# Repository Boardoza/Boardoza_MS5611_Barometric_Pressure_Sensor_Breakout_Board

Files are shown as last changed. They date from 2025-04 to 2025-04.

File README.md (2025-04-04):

# Boardoza MS5611 Barometric Pressure Sensor Breakout Board

The **Boardoza MS5611** is a **high-precision barometric pressure sensor module** designed for **altitude measurement, weather monitoring, and industrial pressure sensing**. It integrates the **MS5611-01BA03** digital pressure sensor, providing accurate pressure readings with ultra-low power consumption.  

This module operates with **3.3V or 5V**, making it compatible with a wide range of microcontrollers. It communicates via **I<sup>2</sup>C by default**, but can be switched to **SPI mode** using the **PS pin**. The **CSB, SDO, and PS pins operate at 3.3V**, ensuring easy interfacing with low-power microcontrollers.  

## [Click here to purchase!](https://www.ozdisan.com/maker-ve-iot-urunleri/boardoza/boardoza-modulleri/BOARDOZA-MS5611/1202433)

|Front Side|Back Side|
|:---:|:---:|
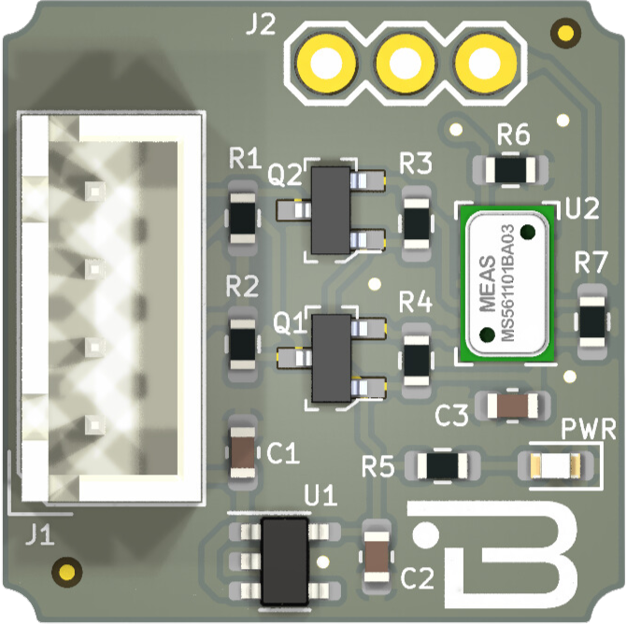
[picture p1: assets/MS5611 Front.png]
MS5611 Front
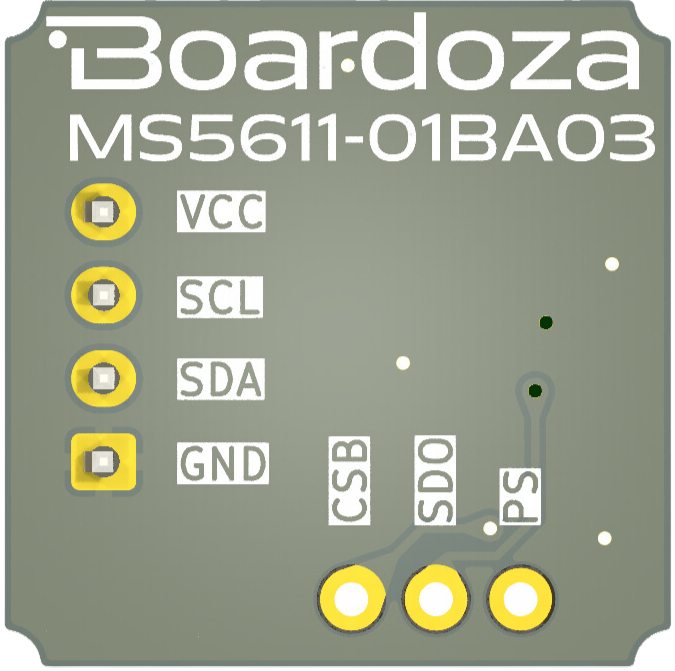
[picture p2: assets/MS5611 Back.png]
MS5611 Back
| | |

---

## Key Features

- **High-Precision Barometric Pressure Sensor:** Ideal for altitude measurement, weather monitoring, and UAV applications.  
- **24-bit High-Resolution Output:** Ultra-precise pressure measurement using an integrated 24-bit ADC.  
- **Flexible Power Compatibility:** Operates with **3.3V or 5V**, making it suitable for various MCUs.  
- **I<sup>2</sup>C and SPI Support:** Default interface is **I<sup>2</sup>C**, but can be configured to **SPI mode** using the **PS pin**.  
- **Ultra-Low Power Consumption:** Optimized for battery-powered applications.  

---

## Technical Specifications

**Model:** MS5611-01BA03  
**Input Voltage:** 3.3V - 5.5V  
**Voltage Input Type:** 4-pin 2.50mm header  
**Interface:** I<sup>2</sup>C (default), SPI (configurable)  
**Functions:** High-Precision Barometric Pressure Measurement  
**ADC Resolution:** 24-bit  
**Operating Pressure Range:** 450 to 1100 mbar (Full Accuracy)  
**Extended Pressure Range:** 10 to 1200 mbar (Linear ADC Range)  
**Operating Temperature:** -40°C ~ +85°C  
**Board Dimensions:** 20mm x 20mm  

---

## Board Pinout

### **( J1 ) I<sup>2</sup>C Communication Pins**  

| Pin Number | Pin Name | Description |
|:---:|:---:|---|
| 1 | VCC | Power Supply (3.3V - 5.5V) |
| 2 | SCL | I<sup>2</sup>C Serial Clock Pin |
| 3 | SDA | I<sup>2</sup>C Serial Data Pin |
| 4 | GND | Ground |

### **( J2 ) SPI Mode & Configuration Pins**  

| Pin Number | Pin Name | Description |
|:---:|:---:|---|
| 1 | CSB | Chip select (active low), internally pulled down to ground with a pull-down resistor. |
| 2 | SDO | Serial data output. |
| 3 | PS | Protocol selection:<ul><li>PS High (3.3V) = I<sup>2</sup>C (Default address: 0x77)</li><li>PS Low (GND) = SPI Mode</li></ul> (Internally pulled up to 3.3V with a pull-up resistor). |

---

## Board Dimensions

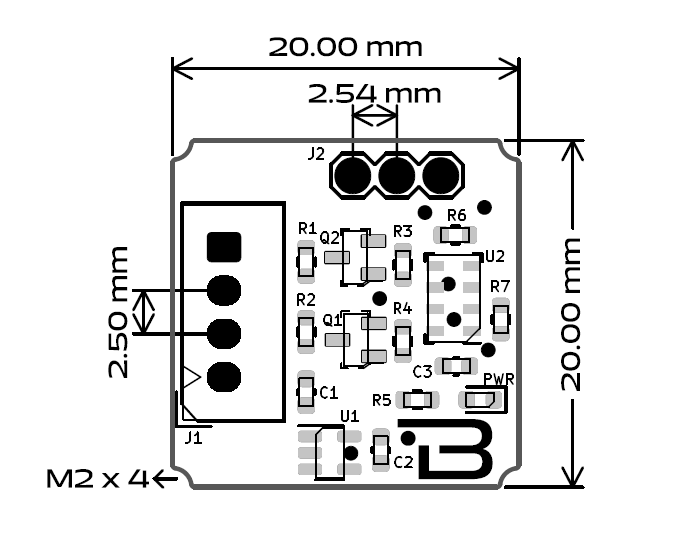
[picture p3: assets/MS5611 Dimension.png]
MS5611 Dimension


---

## Step Files

[Boardoza MS5611.step](./assets/MS5611%20Step.step)

---

## Datasheet

[Boardoza MS5611 Datasheet.pdf](./assets/MS5611%20Datasheet.pdf)

---

## Version History

- V1.0.0 - Initial Release

---

## Support

- If you have any questions or need support, please contact <support@boardoza.com>

---

## License

Shield: [][cc-by-sa]

This work is licensed under a [Creative Commons Attribution-ShareAlike 4.0 International License][cc-by-sa].

[][cc-by-sa]

[cc-by-sa]: http://creativecommons.org/licenses/by-sa/4.0/
[cc-by-sa-image]: https://licensebuttons.net/l/by-sa/4.0/88x31.png
[cc-by-sa-shield]: https://img.shields.io/badge/License-CC%20BY--SA%204.0-lightgrey.svg

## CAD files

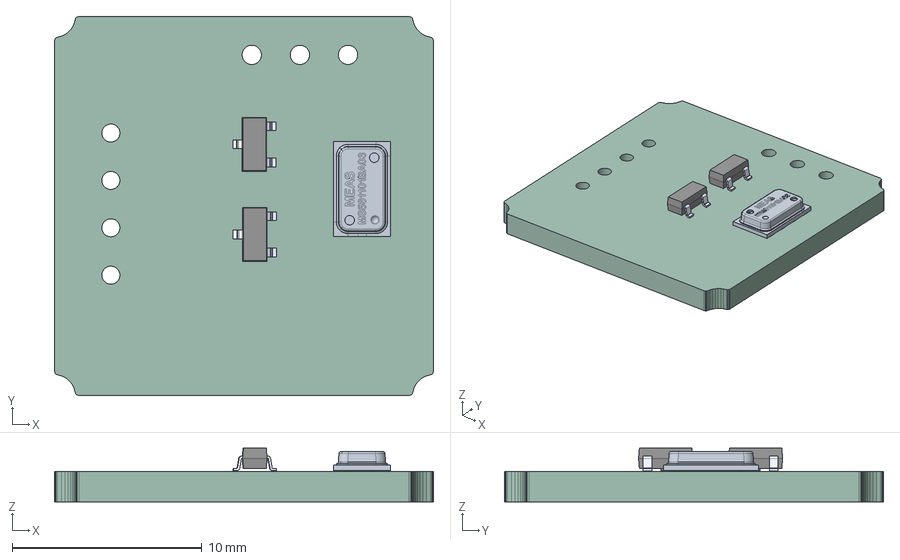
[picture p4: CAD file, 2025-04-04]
assets/MS5611 Step.step
20.0 x 20.0 x 2.83 mm
MAX6103EUR-T x 2
Document
B-MS5611-Brk-01Mbr-R01 PCB

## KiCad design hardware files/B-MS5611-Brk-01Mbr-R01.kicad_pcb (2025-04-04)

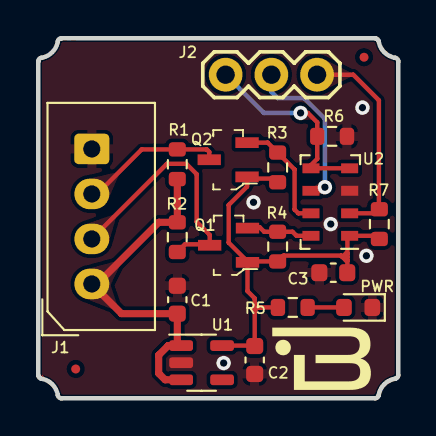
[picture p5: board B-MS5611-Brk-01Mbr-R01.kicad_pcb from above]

Board: 2 copper layers, 20.0 x 20.0 mm, 17 parts (0 on the bottom side), 11 nets.

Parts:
C1, C2: 1uF; C_0603_1608Metric
C3: 100nF; C_0603_1608Metric
J1: MOLEX_CONNECTOR_1X4; 2317-04S_1x04_P2.50mm_Vertical
J2: CONN_03; 1X03
PWR: LED POWER; LED_0603_1608Metric
Q1, Q2: 2N7002_R1_00001; SOT-23-3
R1, R2, R3, R4, R5, R6, R7: 10K; R_0603_1608Metric
U1: TLV73333PDBVR; SOT-23-5
U2: MS5611-01BA; LGA-8_3x5mm_P1.25mm

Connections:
+3V3: C2.1, C3.1, Q1.1 (G), Q2.1 (G), R3.1, R4.1, R5.1, R7.2, U1.5 (OUT), U2.1 (VDD)
CSB: J2.3, R6.1, U2.4 (CSB), U2.5 (CSB)
GND: C1.2, C2.2, C3.2, J1.4, PWR.1 (K), R6.2, U1.2 (GND), U2.3 (GND)
unnamed: PWR.2 (A), R5.2
PS: J2.1, R7.1, U2.2 (PS)
SCL: J1.2, Q1.3 (D), R2.2
SCL_3.3: Q1.2 (S), R4.2, U2.8 (SCLK)
SDA: J1.3, Q2.3 (D), R1.2
SDA_3.3: Q2.2 (S), R3.2, U2.7 (SDI/SDA)
SDO: J2.2, U2.6 (SDO)
VCC: C1.1, J1.1, R1.1, R2.1, U1.1 (IN), U1.3 (EN)

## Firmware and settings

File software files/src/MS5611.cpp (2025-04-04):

#include "MS5611.h"

/**
 * @brief Performs initialization routines.
 *
 * @param osr Oversampling rate for MS5611.
 * @return A boolean value indicating whether the initialization was successful or not.
 *
 * This function initializes the MS5611 sensor and performs necessary initialization routines.
 * First, it starts the Wire library and sends a reset signal to the sensor. Then, it sets
 * the specified oversampling rate and waits for a certain period of time. Finally, it
 * retrieves calibration data and returns a boolean value indicating the success of the operation.
 */
bool MS5611::begin(MS5611_osr osr) {
    Wire.begin();

    performReset();

    setOversampling(osr);

    delay(100);

    getCalibrationData();

    return true;
}

MS5611::MS5611() {
    
}

/**
 * @brief Sets the oversampling rate for the MS5611 sensor.
 *
 * @param osr Oversampling rate to be set.
 *
 * This function sets the oversampling rate for the MS5611 sensor based on the provided parameter.
 * The oversampling rate determines the number of samples taken by the sensor for each measurement,
 * affecting the resolution and accuracy of the readings. The function uses a switch statement to
 * determine the appropriate counter value based on the oversampling rate parameter. The counter
 * value is then assigned to the `counter` member variable and the `userOversamplingRate` member
 * variable is updated with the provided oversampling rate.
 */
void MS5611::setOversampling(MS5611_osr osr) {
    switch (osr)
    {
    case ULTRA_LOW_POWER:
    counter = 1;
        break;
    case LOW_POWER:
    counter = 2;
        break;
    case STANDARD:
    counter = 3;
        break;
    case HIGH_RES:
    counter = 5;
        break;
    case ULTRA_HIGH_RES:
    counter = 10;
        break;
    default:
        break;
    }
    userOversamplingRate = osr;
}

/**
 * @brief Retrieves the current oversampling rate set for the MS5611 sensor.
 *
 * @return The current oversampling rate as an MS5611_osr enum value.
 *
 * This function returns the current oversampling rate that has been set for the MS5611 sensor.
 * The oversampling rate determines the number of samples taken by the sensor for each measurement,
 * affecting the resolution and accuracy of the readings. The function simply returns the value of
 * the `userOversamplingRate` member variable, which holds the current oversampling rate.
 */
uint8_t MS5611::getOversampling(void) {
    return static_cast<uint8_t>(userOversamplingRate);
}

/**
 * @brief Performs a reset operation on the MS5611 sensor.
 *
 * This function sends a reset signal to the MS5611 sensor to perform a reset operation.
 * It starts a transmission using the Wire library to the MS5611 sensor's address and writes
 * the reset command (MS5611_RESET). Finally, it ends the transmission.
 */
void MS5611::performReset(void) {
    Wire.beginTransmission(MS5611_ADDRESS);
    Wire.write(MS5611_RESET);
    Wire.endTransmission();
}

/**
 * @brief Retrieves calibration data from the MS5611 sensor.
 *
 * This function retrieves calibration data from the MS5611 sensor by reading the
 * appropriate registers. It uses a for loop to iterate over the calibration data
 * registers and reads 16 bits of data from each register. The retrieved data is then
 * stored in the `filterCoefficient` array, which holds the calibration coefficients
 * used for sensor measurements.
 */ 
void MS5611::getCalibrationData(void) {
    for(uint8_t offset = 0; offset < 6; offset++) {
        filterCoefficient[offset] = readRegister16(MS5611_READ_PROM + (offset * 2));
    }
}

/**
 * @brief Reads the raw temperature value from the MS5611 sensor.
 *
 * @return The raw temperature value as a 32-bit unsigned integer.
 *
 * This function reads the raw temperature value from the MS5611 sensor. It starts a transmission
 * using the Wire library to the MS5611 sensor's address and writes the conversion command (MS5611_CONV_D2)
 * along with the user-specified oversampling rate. It then ends the transmission and waits for a certain
 * delay based on the oversampling rate. Finally, it reads a 24-bit value from the ADC read register
 * (MS5611_ADC_READ) and returns it as a 32-bit unsigned integer.
 */
uint32_t MS5611::readRawTemperature(void) {
    Wire.beginTransmission(MS5611_ADDRESS);
    Wire.write(MS5611_CONV_D2 + userOversamplingRate);
    Wire.endTransmission();
    delay(counter);
    return readRegister24(MS5611_ADC_READ);
}

/**
 * @brief Reads the raw pressure value from the MS5611 sensor.
 *
 * @return The raw pressure value as a 32-bit unsigned integer.
 *
 * This function reads the raw pressure value from the MS5611 sensor. It starts a transmission
 * using the Wire library to the MS5611 sensor's address and writes the conversion command (MS5611_CONV_D1)
 * along with the user-specified oversampling rate. It then ends the transmission and waits for a certain
 * delay based on the oversampling rate. Finally, it reads a 24-bit value from the ADC read register
 * (MS5611_ADC_READ) and returns it as a 32-bit unsigned integer.
 */
uint32_t MS5611::readRawPressure(void) {
    Wire.beginTransmission(MS5611_ADDRESS);
    Wire.write(MS5611_CONV_D1 + userOversamplingRate);
    Wire.endTransmission();
    delay(counter);
    return readRegister24(MS5611_ADC_READ);
}

/**
 * @brief Reads the temperature from the MS5611 sensor.
 *
 * @param compensation Flag to enable temperature compensation.
 * @return The temperature value as a double.
 *
 * This function reads the temperature from the MS5611 sensor. It first reads the raw temperature value
 * using the `readRawTemperature` function and calculates the temperature difference (dT) by subtracting
 * a scaled coefficient from the raw temperature. It then calculates the temperature using a formula that
 * involves the coefficient and the temperature difference. If compensation is enabled, it checks if the
 * temperature is less than 2000 and calculates an additional temperature correction (temperature2). Finally,
 * it subtracts the temperature correction from the calculated temperature and returns the result as a double,
 * scaled by 100.
 */
double MS5611::readTemperature(bool compensation) {
    uint32_t D2 = readRawTemperature();
    int32_t dT = D2 - (uint32_t)filterCoefficient[4] * 256;

    int32_t temperature = 2000 + ((int64_t) dT * filterCoefficient[5]) / 8388608;

    temperature2 = 0;
    if(compensation) {
        if(temperature2 < 2000) {
            temperature2 = (dT * dT) / pow(2, 31);
        }
    }
    temperature = temperature - temperature2;

    return ((double)temperature/100);
}
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

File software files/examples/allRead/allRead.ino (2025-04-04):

#include "MS5611.h"

MS5611 sensor;

void setup() {
  Serial.begin(115200);

  // Initialize sensor
  if(sensor.begin(ULTRA_HIGH_RES)) {
    Serial.println("MS5611 initiated.");
  } else {
    Serial.println("MS5611 failed to start.");
    while(1); // Stay in loop if sensor fails to initialize
  }
}

void loop() {
  // Read and print the temperature value
  double temperature = sensor.readTemperature(true); // Read the temperature value (compensate)
  Serial.print("Temperature: ");
  Serial.print(temperature);
  Serial.print(" C  ");

  // Read and print the pressure value
  int32_t pressure = sensor.readPressure(true); // Read the pressure value (compensate)
  Serial.print("Pressure: ");
  Serial.print(pressure);
  Serial.print(" Pa ");

  // Calculate and print the pressure value at sea level
  double seaLevelPressure = 101325; // Example: 101325 Pa
  double altitude = sensor.getAltitude(pressure, seaLevelPressure); // Calculate height
  Serial.print("Altitude: ");
  Serial.print(altitude);
  Serial.println(" m");

  delay(1000); // Wait for 1 second
}
